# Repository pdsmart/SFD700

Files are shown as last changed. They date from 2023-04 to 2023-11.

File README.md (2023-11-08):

# SFD-700

Repository updated 08/11/2023

v1.0 - Functions in most machines, albeit, for an MZ-700 it requires MZ-700 memory mapping logic if used outside of an MZ-1U06 expansion box. Recommend only to view, not to build.

v1.1 - Functions but restrictions imposed with the GAL registers (ie. one clock all register) it couldnt satisfy my latest requirements, ie. MZ-700 memory mapping logic and Flash ROM paging. - Recommend only to view, not to build.

v1.2 - Hardware functions well on all machines tested (MZ-80A, MZ-700, MZ-1500, MZ-2000) and updates made to the Rom Filing System which basically works but has a few bugs I need to work out (fully functions as an FDC just the ROM based component of RFS has a bug and also I want to add FDC commands to the RFS Monitor). Also started updating CP/M and Basic (SA-5510, NASCOM Basic etc).

Documentation needs to be updated as it is out of date on my website, wip!

A Floppy Disk Interface card for the Sharp MZ series of machines (MZ-80B/MZ-80A/MZ-700/MZ-800/MZ-1500/MZ-2000/MZ-2200).

This project is based on an iconic floppy disk interface card from the 1980's by the Aachen based company, Kersten & Partner GmbH. The company produced two cards,
the SFD-700 for the Sharp MZ-700 and the SFD-800 for the Sharp MZ-800. 

Owning an original SFD-800, I reproduced the SFD-800 from the original schematic and the design can be seen here: https://eaw.app/sfd800/. This card has been well
tested and as the SFD-800 was quite a flexible design, it also worked in the MZ-80B/MZ-800/MZ-1500/MZ-2000/MZ-2200 computers. Unfortunately it didnt cater for the Sharp MZ-700 or indeed the Sharp MZ-80A.

To address the requirement of a floppy interface for the Sharp MZ-700 and MZ-80A, I considered reproducing the SFD-700 exactly but analysis showed it wouldnt work in an MZ-80A which uses a hardware trick to
address the CPU speed shortcomings. I thus decided, based on the SFD-800 schematics, to create a version 2 of the SFD-700 design which would work in all the Sharp MZ series computers.

Please see my website (in due course), https://eaw.app for more documentation and any recent updates.

If you want to build a v1.2 card, I have 6 boards spare I can ship, just pay me for the postage.

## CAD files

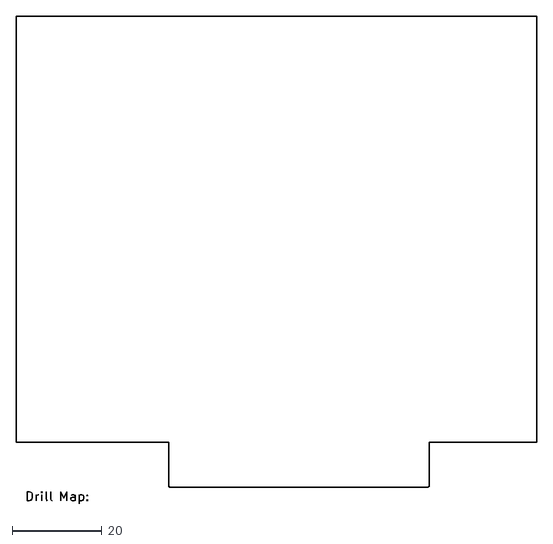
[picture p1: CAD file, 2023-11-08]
kicad/Output/v1.2/SFD700-NPTH-drl_map.dxf
116.0 x 108.6

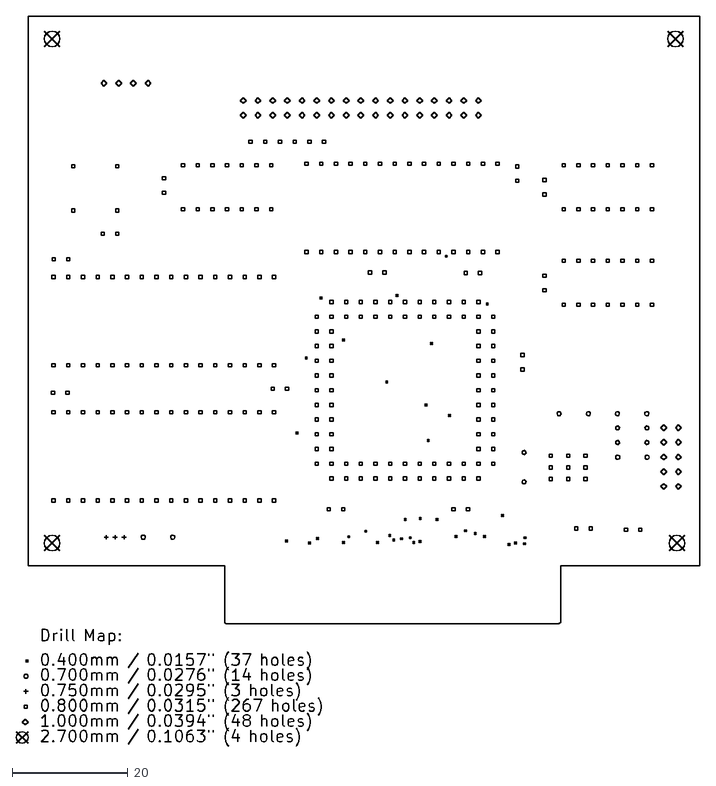
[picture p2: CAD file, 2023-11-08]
kicad/Output/v1.2/SFD700-PTH-drl_map.dxf
118.0 x 126.1

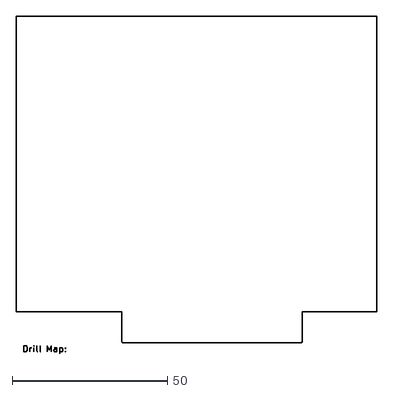
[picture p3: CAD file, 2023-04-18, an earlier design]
kicad/Output/v1.0/SFD700-NPTH-drl_map.dxf
116.0 x 108.6

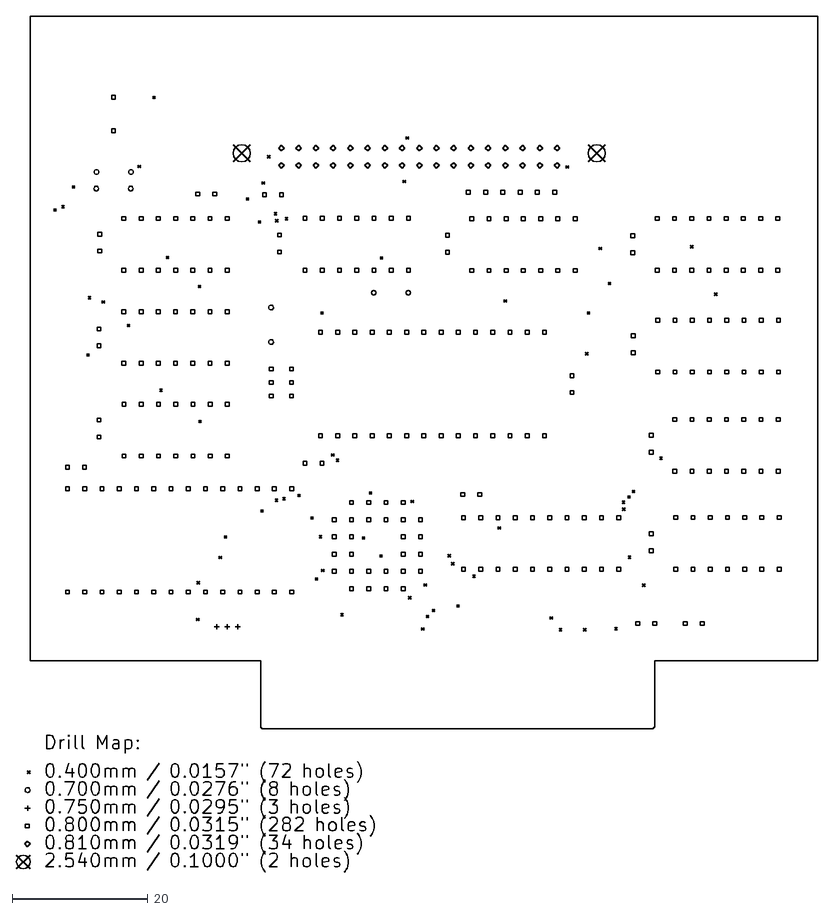
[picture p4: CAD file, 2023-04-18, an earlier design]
kicad/Output/v1.0/SFD700-PTH-drl_map.dxf
118.0 x 126.1

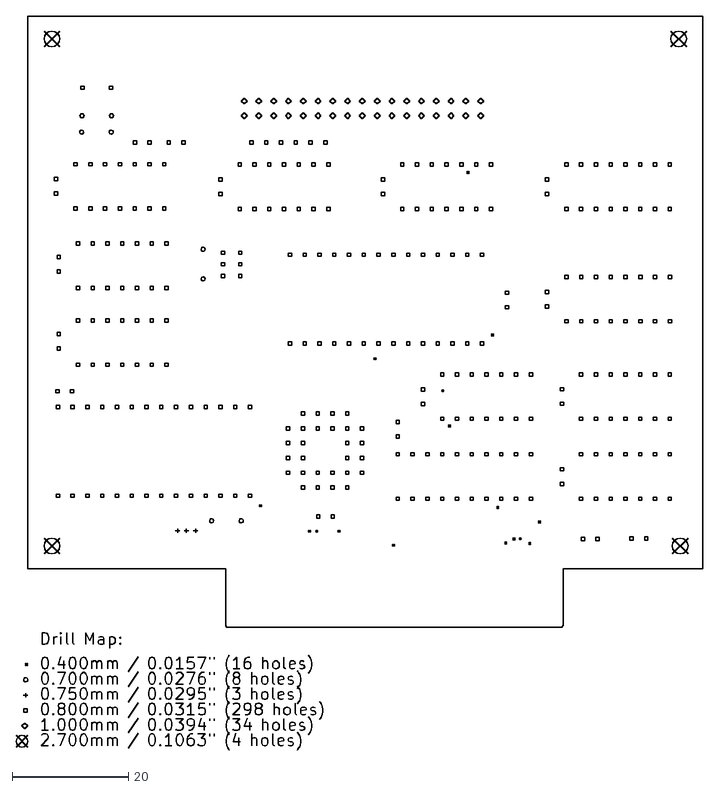
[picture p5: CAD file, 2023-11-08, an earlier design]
kicad/Output/v1.1/SFD700-PTH-drl_map.dxf
118.0 x 126.1

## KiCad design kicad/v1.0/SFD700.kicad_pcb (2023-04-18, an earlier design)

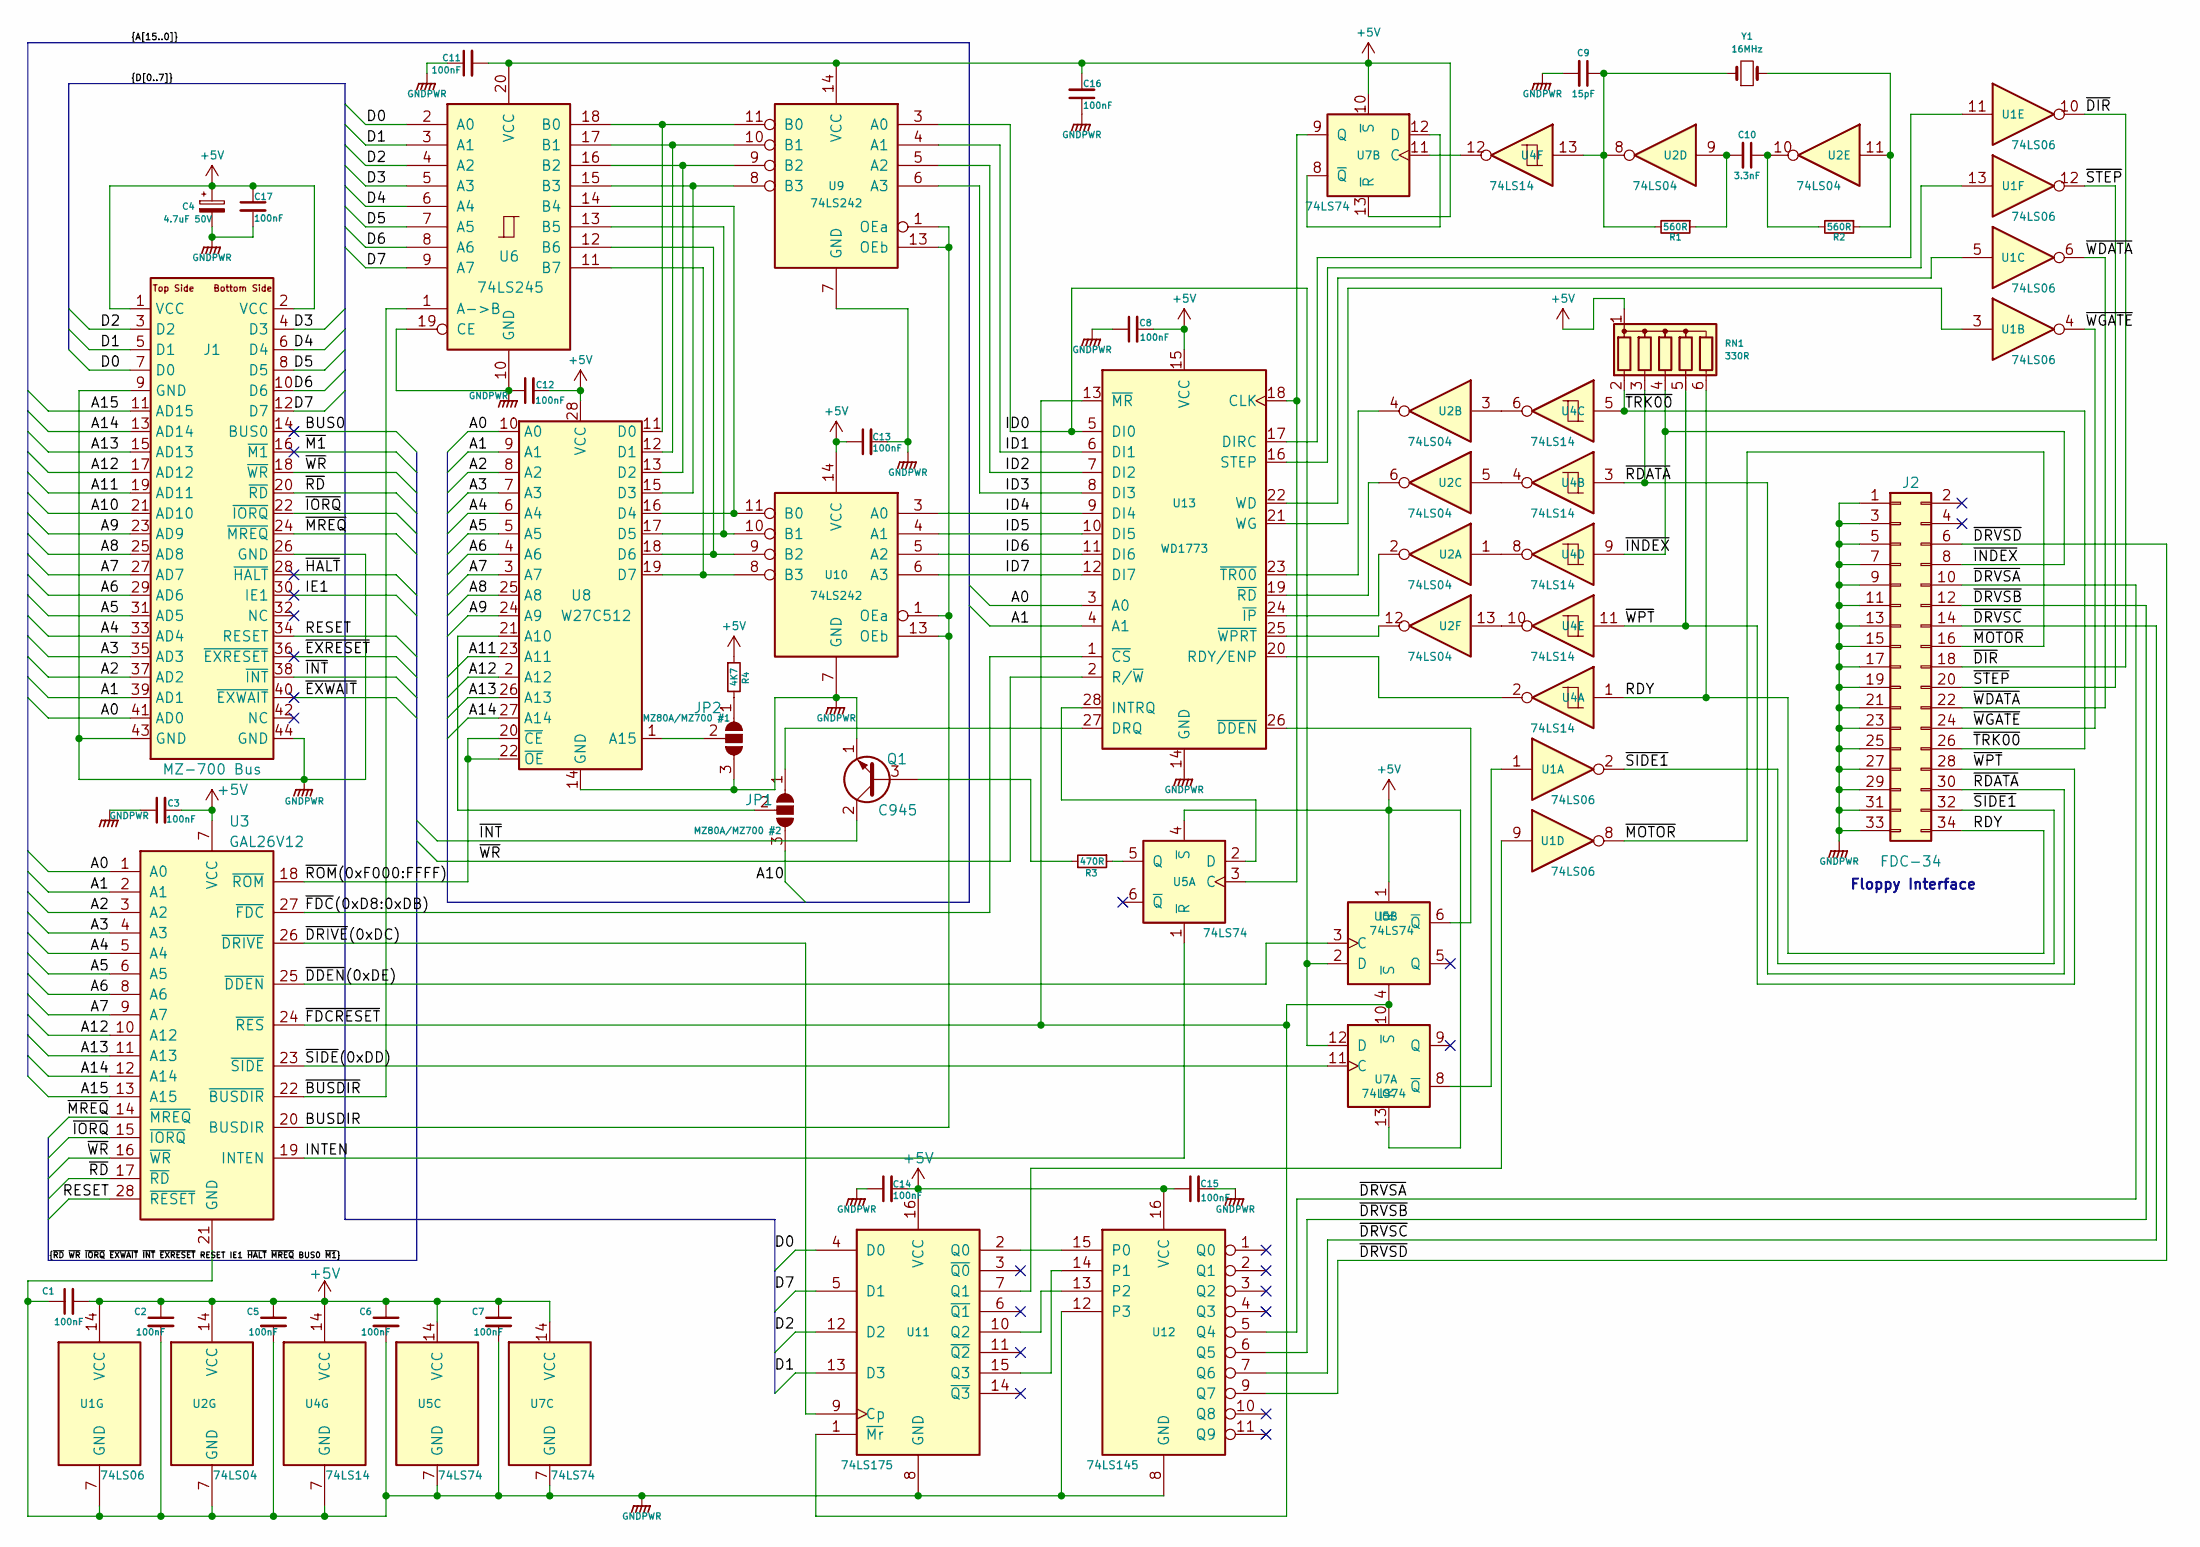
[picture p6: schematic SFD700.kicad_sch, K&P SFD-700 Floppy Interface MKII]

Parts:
C1, C2, C3, C5, C6, C7, C8, C11, C12, C13, C14, C15, C16, C17: 100nF; C_Disc_D5.0mm_W2.5mm_P2.50mm
C4: 4.7uF 50V; C_Radial_D6.3mm_H5.0mm_P2.50mm
C9: 15pF; C_Disc_D5.0mm_W2.5mm_P2.50mm
C10: 3.3nF; C_Disc_D5.0mm_W2.5mm_P2.50mm
J1: MZ-700 Bus; BUS_MZ800
J2: FDC-34; IDC-Header_2x17_P2.54mm_Horizontal_Lock_SFD700
JP1: MZ80A/MZ700 #2; PinHeader_1x03_P2.00mm_Vertical
JP2: MZ80A/MZ700 #1; PinHeader_1x03_P2.00mm_Vertical
Q1: C945; TO-92_Inline
R1, R2: 560R; R_Axial_DIN0204_L3.6mm_D1.6mm_P5.08mm_Horizontal
R3: 470R; R_Axial_DIN0204_L3.6mm_D1.6mm_P5.08mm_Horizontal
R4: 4K7; R_Axial_DIN0204_L3.6mm_D1.6mm_P5.08mm_Horizontal
RN1: 330R; R_Array_SIP6
U1: 74LS06; DIP-14_W7.62mm
U2: 74LS04; DIP-14_W7.62mm
U3: GAL26V12; PLCC-28_THT-Socket
U4: 74LS14; DIP-14_W7.62mm
U5, U7: 74LS74; DIP-14_W7.62mm
U6: 74LS245; DIP-20_W7.62mm
U8: W27C512; DIP-28_W15.24mm
U9, U10: 74LS242; DIP-14_W7.62mm
U11: 74LS175; DIP-16_W7.62mm
U12: 74LS145; DIP-16_W7.62mm
U13: WD1773; DIP-28_W15.24mm
Y1: 16MHz; Crystal_HC18-U_Vertical

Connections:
+5V: C1.2, C2.1, C3.2, C4.1, C5.1, C6.1, C7.1, C8.2, C11.2, C12.2, C13.1, C14.2, C15.1, C16.2, C17.1, J1.1 (VCC), J1.2 (VCC), R4.1, RN1.1 (common), U1.14 (VCC), U2.14 (VCC), U3.7 (VCC), U4.14 (VCC), U5.4 (~S), U5.13 (~R), U5.14 (VCC), U6.20 (VCC), U7.1 (~R), U7.10 (~S), U7.13 (~R), U7.14 (VCC), U8.28 (VCC), U9.14 (VCC), U10.14 (VCC), U11.16 (VCC), U12.16 (VCC), U13.15 (VCC)
/A0: J1.41 (AD0), U3.1 (A0), U8.10 (A0), U13.3 (A0)
/A1: J1.39 (AD1), U3.2 (A1), U8.9 (A1), U13.4 (A1)
/A2: J1.37 (AD2), U3.3 (A2), U8.8 (A2)
/A3: J1.35 (AD3), U3.4 (A3), U8.7 (A3)
/A4: J1.33 (AD4), U3.5 (A4), U8.6 (A4)
/A5: J1.31 (AD5), U3.6 (A5), U8.5 (A5)
/A6: J1.29 (AD6), U3.8 (A6), U8.4 (A6)
/A7: J1.27 (AD7), U3.9 (A7), U8.3 (A7)
/A8: J1.25 (AD8), U8.25 (A8)
/A9: J1.23 (AD9), U8.24 (A9)
/A10: J1.21 (AD10), JP1.3 (B)
/A11: J1.19 (AD11), U8.23 (A11)
/A12: J1.17 (AD12), U3.10 (A12), U8.2 (A12)
/A13: J1.15 (AD13), U3.11 (A13), U8.26 (A13)
/A14: J1.13 (AD14), U3.12 (A14), U8.27 (A14)
/A15: J1.11 (AD15), U3.13 (A15)
/BUS0: J1.14 (BUS0)
/BUSDIR: U3.20 (BUSDIR), U9.1 (OEa), U9.13 (OEb), U10.1 (OEa), U10.13 (OEb)
/D0: J1.7 (D0), U6.2 (A0), U11.4 (D0)
/D1: J1.5 (D1), U6.3 (A1), U11.13 (D3)
/D2: J1.3 (D2), U6.4 (A2), U11.12 (D2)
/D3: J1.4 (D3), U6.5 (A3)
/D4: J1.6 (D4), U6.6 (A4)
/D5: J1.8 (D5), U6.7 (A5)
/D6: J1.10 (D6), U6.8 (A6)
/D7: J1.12 (D7), U6.9 (A7), U11.5 (D1)
/ID0: U5.12 (D), U7.2 (D), U9.3 (A0), U13.5 (DI0)
/ID1: U9.4 (A1), U13.6 (DI1)
/ID2: U9.5 (A2), U13.7 (DI2)
/ID3: U9.6 (A3), U13.8 (DI3)
/ID4: U10.3 (A0), U13.9 (DI4)
/ID5: U10.4 (A1), U13.10 (DI5)
/ID6: U10.5 (A2), U13.11 (DI6)
/ID7: U10.6 (A3), U13.12 (DI7)
/IE1: J1.30 (IE1)
/INTEN: U3.19 (INTEN), U5.1 (~R)
/RDY: J2.34, RN1.6 (R5), U4.1
/RESET: J1.34 (RESET), U3.28 (~RESET)
/~BUSDIR: U3.22 (~BUSDIR), U6.1 (A->B)
/~DDEN(0xDE): U3.25 (~DDEN), U7.3 (C)
/~DIR: J2.18, U1.10
/~DRIVE(0xDC): U3.26 (~DRIVE), U11.9 (Cp)
/~DRVSA: J2.10, U12.5 (Q4)
/~DRVSB: J2.12, U12.6 (Q5)
/~DRVSC: J2.14, U12.7 (Q6)
/~DRVSD: J2.6, U12.9 (Q7)
/~EXRESET: J1.36 (~EXRESET)
/~EXWAIT: J1.40 (~EXWAIT)
/~FDCRESET: U3.24 (~RES), U5.10 (~S), U7.4 (~S), U11.1 (~Mr), U13.13 (~MR)
/~FDC(0xD8:0xDB): U3.27 (~FDC), U13.1 (~CS)
/~HALT: J1.28 (~HALT)
/~INDEX: J2.8, RN1.4 (R3), U4.9
/~INT: J1.38 (~INT), Q1.2 (C)
/~IORQ: J1.22 (~IORQ), U3.15 (~IORQ)
/~M1: J1.16 (~M1)
/~MOTOR: J2.16, U1.8
/~MREQ: J1.24 (~MREQ), U3.14 (~MREQ)
/~RDATA: J2.30, RN1.3 (R2), U4.3
/~RD: J1.20 (~RD), U3.17 (~RD)
/~ROM(0xF000:FFFF): U3.18 (~ROM), U8.20 (~CE), U8.22 (~OE)
/~SIDE1: J2.32, U1.2
/~SIDE(0xDD): U3.23 (~SIDE), U5.11 (C)
/~STEP: J2.20, U1.12
/~TRK00: J2.26, RN1.2 (R1), U4.5
/~WDATA: J2.22, U1.6
/~WGATE: J2.24, U1.4
/~WPT: J2.28, RN1.5 (R4), U4.11
/~WR: J1.18 (~WR), U3.16 (~WR), U13.2 (R/~W)
GNDPWR: C1.1, C2.2, C3.1, C4.2, C5.2, C6.2, C7.2, C8.1, C9.2, C11.1, C12.1, C13.2, C14.1, C15.2, C16.1, C17.2, J1.9 (GND), J1.26 (GND), J1.43 (GND), J1.44 (GND), J2.1, J2.3, J2.5, J2.7, J2.9, J2.11, J2.13, J2.15, J2.17, J2.19, J2.21, J2.23, J2.25, J2.27, J2.29, J2.31, J2.33, JP2.3 (B), Q1.1 (E), U1.7 (GND), U2.7 (GND), U3.21 (GND), U4.7 (GND), U5.7 (GND), U6.10 (GND), U6.19 (CE), U7.7 (GND), U8.14 (GND), U9.7 (GND), U10.7 (GND), U11.8 (GND), U12.8 (GND), U12.12 (P3), U13.14 (GND)
unnamed: C9.1, R1.2, U2.8, U4.13, Y1.1
unnamed: C10.1, R2.2, U2.10
unnamed: C10.2, R1.1, U2.9
unnamed: JP1.1 (A), U13.27 (DRQ)
unnamed: JP1.2 (C), U8.21 (A10)
unnamed: JP2.1 (A), R4.2
unnamed: JP2.2 (C), U8.1 (A15)
unnamed: Q1.3 (B), R3.2
unnamed: R2.1, U2.11, Y1.2
unnamed: U2.1, U4.8
unnamed: U2.3, U4.6
unnamed: U2.5, U4.4
unnamed: U2.13, U4.10
unnamed: R3.1, U5.5 (Q)
unnamed: U1.1, U5.8 (~Q)
unnamed: U6.18 (B0), U8.11 (D0), U9.11 (B0)
unnamed: U6.17 (B1), U8.12 (D1), U9.10 (B1)
unnamed: U6.16 (B2), U8.13 (D2), U9.9 (B2)
unnamed: U6.15 (B3), U8.15 (D3), U9.8 (B3)
unnamed: U4.12, U7.11 (C)
unnamed: U7.8 (~Q), U7.12 (D)
unnamed: U6.14 (B4), U8.16 (D4), U10.11 (B0)
unnamed: U6.13 (B5), U8.17 (D5), U10.10 (B1)
unnamed: U6.12 (B6), U8.18 (D6), U10.9 (B2)
unnamed: U6.11 (B7), U8.19 (D7), U10.8 (B3)
unnamed: U11.2 (Q0), U12.15 (P0)
unnamed: U1.9, U11.7 (Q1)
unnamed: U11.10 (Q2), U12.13 (P2)
unnamed: U11.15 (Q3), U12.14 (P1)
unnamed: U5.3 (C), U7.9 (Q), U13.18 (CLK)
unnamed: U1.11, U13.17 (DIRC)
unnamed: U5.2 (D), U13.28 (INTRQ)
unnamed: U4.2, U13.20 (RDY/ENP)
unnamed: U1.13, U13.16 (STEP)
unnamed: U1.5, U13.22 (WD)
unnamed: U1.3, U13.21 (WG)
unnamed: U7.6 (~Q), U13.26 (~DDEN)
unnamed: U2.2, U13.24 (~IP)
unnamed: U2.6, U13.19 (~RD)
unnamed: U2.4, U13.23 (~TR00)
unnamed: U2.12, U13.25 (~WPRT)

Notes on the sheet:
Floppy Interface

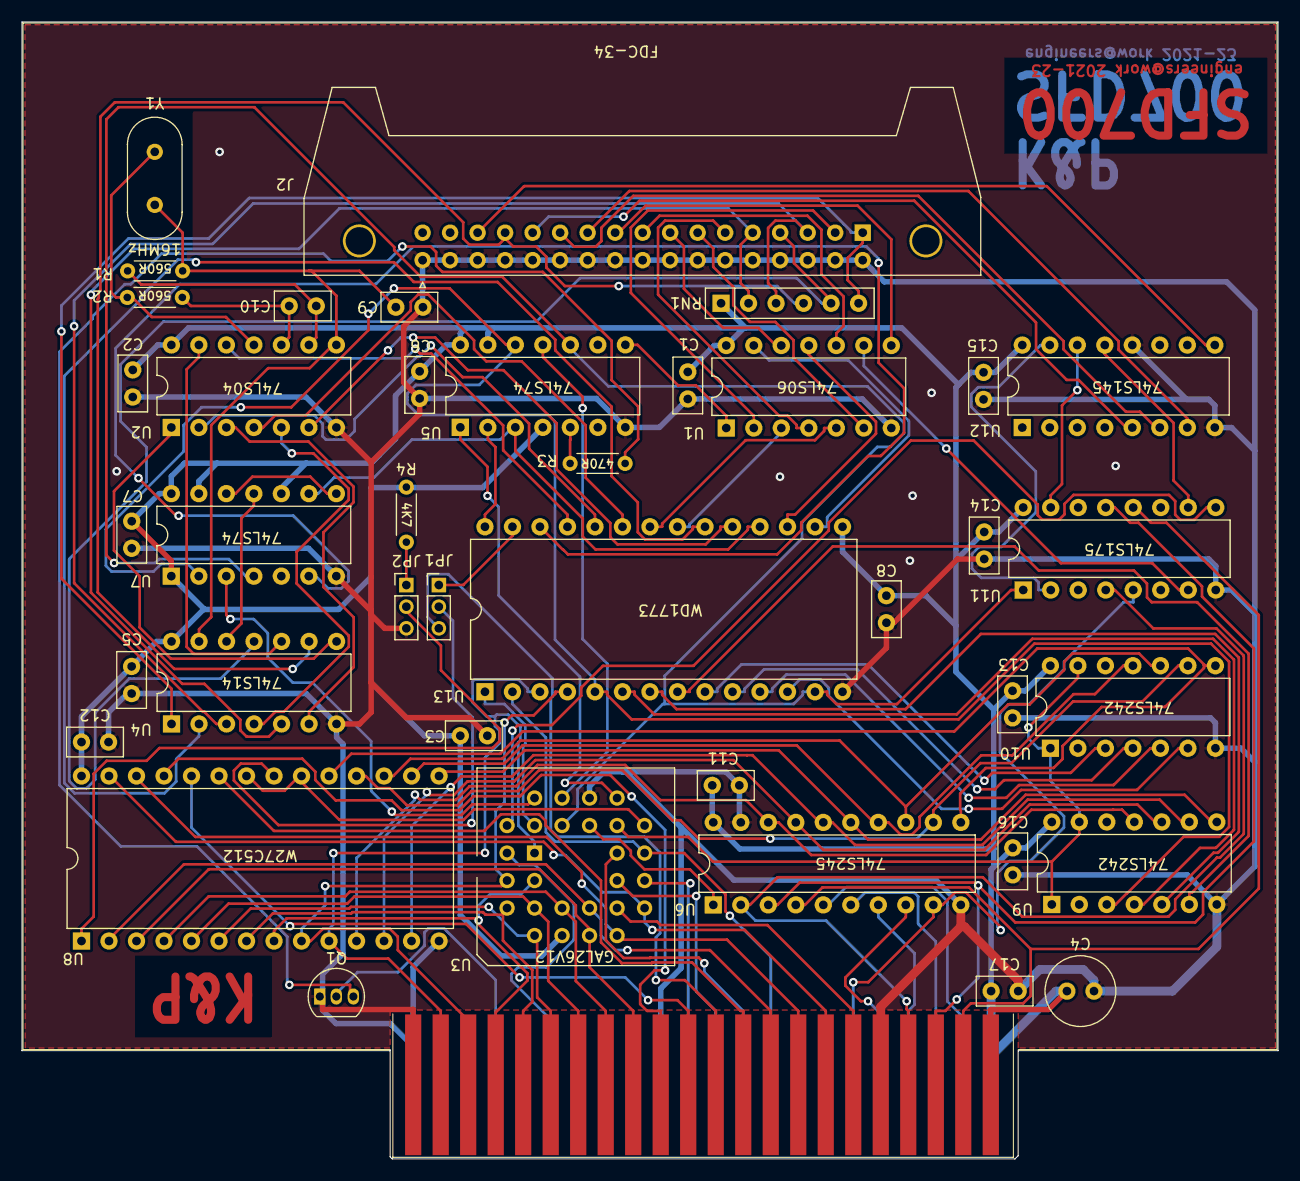
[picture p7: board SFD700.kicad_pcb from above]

Board: 2 copper layers, 116.0 x 105.0 mm, 41 parts (0 on the bottom side), 105 nets.

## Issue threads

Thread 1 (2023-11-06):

SFD-700 - Question about interrupt line

alex3331, 2023-11-06:
Hello,
do I need interrupt cirquit if I use MZ-700 which is fast enough?
and - do I need port DE if there is no addressing of it?

pdsmart, 2023-11-06:
I've updated the readme, the design in github is v1.0 and old, there were problems with it and I created v1.1 and v1.2, v1.2 being stable. I will update github in due course.

The MZ series dont use the interrupt line only my versions of CP/M and firmware derivatives such as Nascom Basic use the interrupt. The circuit was developed to be compatible with all the MZ machines from MZ-80A to MZ-2200. It may work on the MZ-80K (using later floppy firmware - MZ-80K used a different FDC controller).

alex3331, 2023-11-07:
Thank you very much for your update. **Can you please confirm that for MZ-700 the DE port is not needed?**
My objective is a lot more modest - I need to build just  a floppy controller for MZ-700 only and be able to use a 3.5" 720 k floppy to store and load .mzf files. I beleive the program called Supercopy will allow me to do this.  So I just need to build a controller with a 'textbook' use of 1773 or 2793, added ports DC (motor+drive select) and DD (side) and a 2 kiB ROM with some form of IPL. I may need to delay READY signal like in MZ-1E05 with 74LS122 monovibrator. Do you think  this is a reasonable approach?
Thank you.

pdsmart, 2023-11-07:
DE is only needed if you want to dynamically set the disk density. It should be strapped to 0V (GND) for normal double density use or pulled high for single density. Best to use a jump so gives you the choice if you come across any media recorded in single density.

A point to bear in mind with the MZ-700 is the memory mapping logic which pages in/out ROM/RAM. If you add a 2K rom on an external card but do not mirror the memory mapping logic then you would end up with a lot of programs not working if they depended on upper RAM (as both RAM and ROM would be paged in simultaneously). If you use an expansion box from Sharp such as the MZ-1U06 then this contains the memory mapping logic and would disable access to any rom based on a card as necessary.

alex3331, 2023-11-08:
Thank you for your response. I am well aware of memory mapping in MZ-700. I designed my own backplane instead of antique MZ-1U6. It has a monitor ROM including MZ 1-013 and optional high monitor E010 -FFFF, which is controlled by 1502 CPLD. At this point I just need a working FDC. So I can put a ROM in F000 area for now.

pdsmart, 2023-11-08:
If you already have the backplane with space to add a rom, you could just build the SFD800 which is tried and tested and working. It works in the MZ700 just so long as you have the MZ-1E05 ROM at 0xF000.

I will push my latest updates on this project this week, it is wip, but the v1.2 card works in all machines, probably overkill for your project but fully working. I just havent completed all the Z80 firmware as I built in my RFS monitor framework to the card and was in the process of updating my version of CP/M, BASIC etc to work with it.

alex3331, 2023-11-08:
Makes sense! The only problem - I dio not have access to LS242; I planned to use HCT640 instead. But maybe it will be easier to buy 242. Thanks.

alex3331, 2023-11-22:
I assembled SFD-800 and connected to my MZ-800. Which disk would you recommend to try? I have some images of C/PM 4.1 but all show loading errors. It may be a bad disk(s) or controller malfuncitioning. Is it possible to create a floppy from image to test the device?

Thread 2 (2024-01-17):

some guidance

rickyelqasem, 2024-01-17:
few questions:

- I can see the 2 pld files for the GAL chips but what is SFD700_2.PLD.MZ700 for?
- what are the CPLD files for? there doesn't seem to be a CPLD chip
- want to build these for mz700 m in terms of roms I can I just flash SFD700.rom and all will work?

thanks for your efforts.

rickyelqasem, 2024-01-29:
and how did you program the 26CV12 chip... very difficult to find info on this..  I have a TL866-2 plus... noting on 26CV12

pdsmart, 2024-01-29:
Hi, my appologies, I havent had time to look at my projects for 6 months now due to a very demanding contract.

The early versions of this card uses the GAL's but then the latest version I switched to a CPLD. The earlier versions had issues due to lack of logic in the GAL, hence switching. The CPLD is the same cost as the GAL's.

The 26CV12 I programmed via a made up interface and reconfig of the TL866-II software.

The latest version, v1.2 which uses the CPLD is fully working as a disk controller and most of the enhanced rom functions work too, just a few minor bugs and additional commands I want to add havent yet been addressed.

If you download the v1.2 kicad schematics and PCB (there is my working PCB board in the releases) and for the CPLD, download Altera (Intel) Quartus II v13.0 to assemble and program the CPLD.

Hopefully I will get time in the next few months to start finishing the SFD700 and the tranzputerPico (a plug in Z80 replacement based on the ESP32 chip)! Everything though, apart from documentation is stored in the repo as to my latest stage.

thecaver99, 2025-07-30:
do you have the information on the interface and the config files for the tl866 to program the gal26 chips please.

pdsmart, 2025-08-08:
[tl866.tar.gz](https://github.com/user-attachments/files/21682897/tl866.tar.gz)
This is my Linux build of the tool to program the GAL with the TL866. This is how I would program it:
minipro --infoic /dvlp/Projects/minipro/infoic.xml -p GAL26CV12 -w SFD700_G.JED

Not sure of the Windows version but the xml file is the same, so you should be able to take it and update the windows XML and program from the GUI.

The GAL chip version though I never got to fully work, it worked as a basic FD controller but not enhanced ROM like I was hoping for, hence moving on to the CPLD. Hence version 1.2, this works correctly, the only outstanding bug was in the ROM RFS software which I never got time to resolve. Doesnt affect the card working just if using the RFS dir command to list the onboard ROM filing system contents.

thecaver99, 2025-08-08:
Hi Philip,

thanks for the info, i have a linux box and can have a look, a standard fd
controller would be great as it is.
Thank you for the tl866 file, i will give this a go once i order a gla26.
i can lookk at the cpld version  as well.
i have both mz-800 and mz-700, and i am looking forwrd to being able to use
the floppy drives as though i was back in 1984 whyen i had my original 700
and lusted after a qd let alond floppy lol.

If you do manage to find any bits please let me know as i would be very
interested in them.

Kind Regards
Graham

On Fri, Aug 8, 2025 at 12:59 PM Philip Smart ***@***.***>
wrote:

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

thecaver99, 2025-08-21:
Hi Philip,

ive just received some of the 1.2 boards (cpld version), by any chance do
you have a bom and schematic for this version, the one on your web site is
got the gal version.
and i know this is very cheeky but would you by any chance have a copy of
the compiled gal26 code still?

Regards

Graham

<http://www.avg.com/email-signature?utm_medium=email&utm_source=link&utm_campaign=sig-email&utm_content=webmail>
Virus-free.www.avg.com
<http://www.avg.com/email-signature?utm_medium=email&utm_source=link&utm_campaign=sig-email&utm_content=webmail>
<#DAB4FAD8-2DD7-40BB-A1B8-4E2AA1F9FDF2>

On Fri, Aug 8, 2025 at 12:59 PM Philip Smart ***@***.***>
wrote:

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

pdsmart, 2025-08-31:
Hi, the last email I sent you has links to download my repo as a zip file, please use those and I’ll also look to ensuring github is in sync with my local repo.

pdsmart, 2025-09-01:
I've just made a sync, no differences to my repo except Kicad updated to v8, no changes in schematics/pcb, also added the GAL CUPL intermediate compiled files. Otherwise everything is in sync with my repo.
Software is in the RFS repository, if you want to add RFS to the board.

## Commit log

2023-04-18 First release
    [SFD700-B_Cu.gbr, SFD700-B_Mask.gbr, SFD700-B_Paste.gbr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]
2023-11-08 Updates since v1.0
    [Logic.kicad_sch, PowerDecoupling.kicad_sch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]
2023-11-08 Updates from v1.0
    [SFD700.kicad_pcb, SFD700.kicad_sch]
2025-09-01 Added GAL compiled files
    [Logic.kicad_sch, PowerDecoupling.kicad_sch, SFD700.kicad_sch]
